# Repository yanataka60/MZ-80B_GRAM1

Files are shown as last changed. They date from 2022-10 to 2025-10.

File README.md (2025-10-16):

# MZ-80B GRAM1ボード

　MZ-80B OWNER'S MANUAL p65「図4-19 グラフィックメモリ1 MZ-8BG(オプション)」回路図から基板を起こしました。

　本体への装着方法は純正品と同じです。

## 回路図
　KiCadフォルダ内のMZ-80B_GRAM1.pdf参照

[回路図](https://github.com/yanataka60/MZ-80B_GRAM1/blob/main/KiCAD/MZ-80B_GRAM1.pdf)
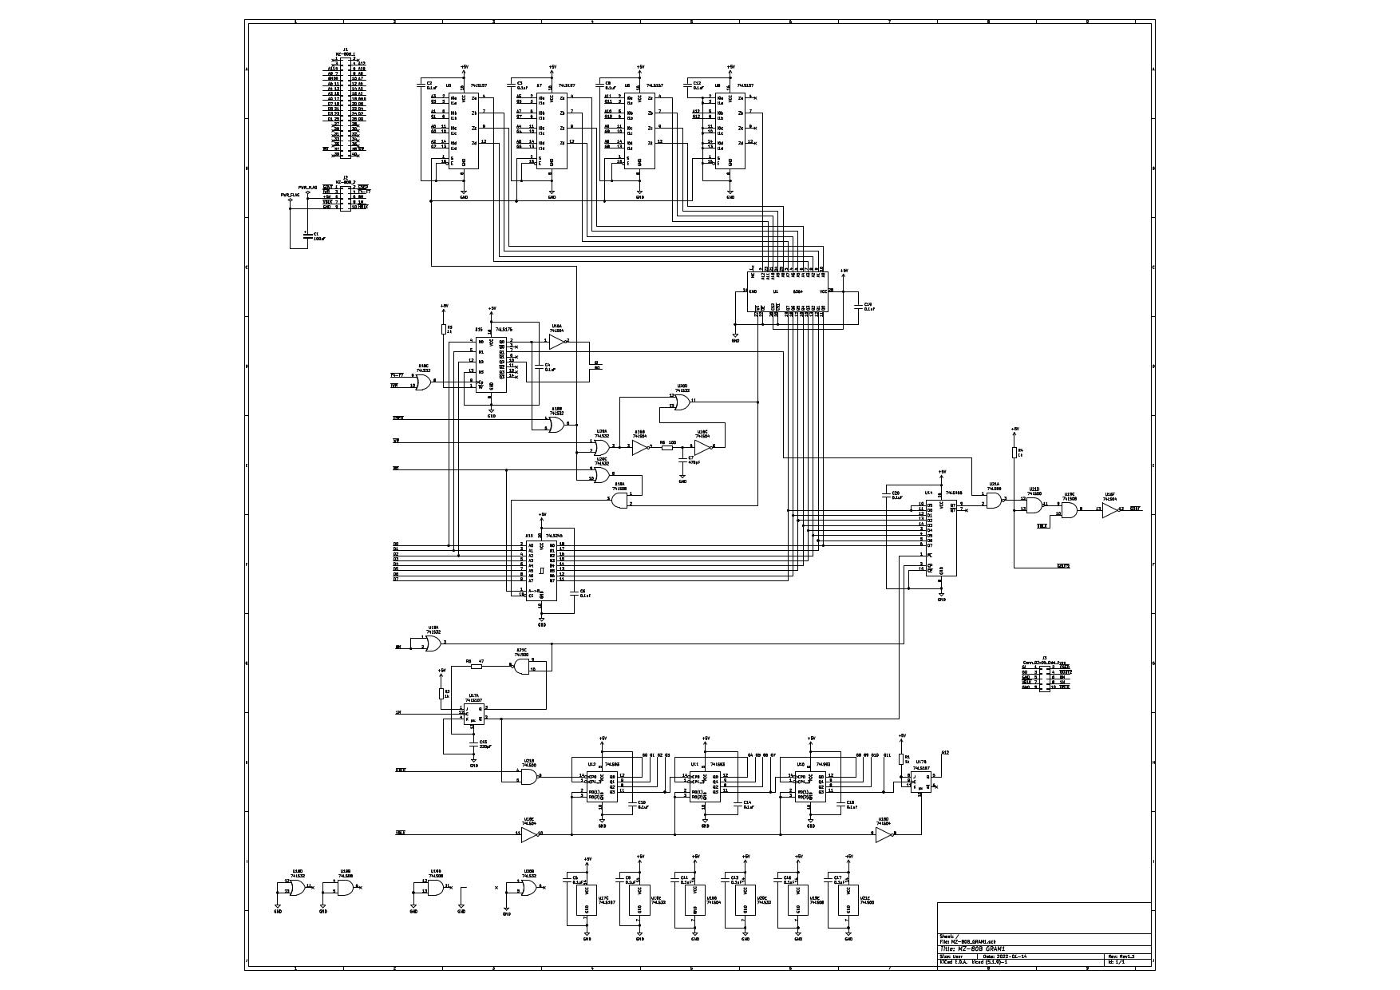
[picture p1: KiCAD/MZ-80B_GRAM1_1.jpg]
回路図


## 部品表
|番号|品名|数量|備考|
| --- | --- | --- | --- |
|C1|電解コンデンサ 16V100uF|1||
|C2-C6, C8-C14, C16-C20|積層セラミックコンデンサ 0.1uF|17||
|C7|コンデンサ 470pF|1||
|C15|コンデンサ 220pF|1||
|J1|2x20ピンヘッダ|1|秋月電子通商 PH-2x40SG等|
|J2|2x5ピンヘッダ|2|秋月電子通商 PH-2x40SG等|
|J3|2x5ピンヘッダ|2|GRAM2接続用 秋月電子通商 PH-2x40SG等|
|R1-R4|カーボン抵抗 1k|4||
|R5|カーボン抵抗 47Ω|1||
|R6|カーボン抵抗 100Ω|1||
|U1|8kx8 SRAM 6264|1|若松通商等|
|U5-U8|74LS157|4|若松通商等|
|U10-U12|74LS93|3|若松通商等|
|U13|74LS245|1|若松通商等|
|U14|74LS165|1|若松通商等|
|U15|74LS175|1|若松通商等|
|U16|74LS04|1|若松通商等|
|U17|74LS107|1|若松通商等|
|U18, U20|74LS32|2|若松通商等|
|U19|74LS08|1|若松通商等|
|U21|74LS00|1|若松通商等|
||2x20フラットケーブル|1|15cm程度|
||2x5フラットケーブル|1|20cm程度|

## ボードの完成写真
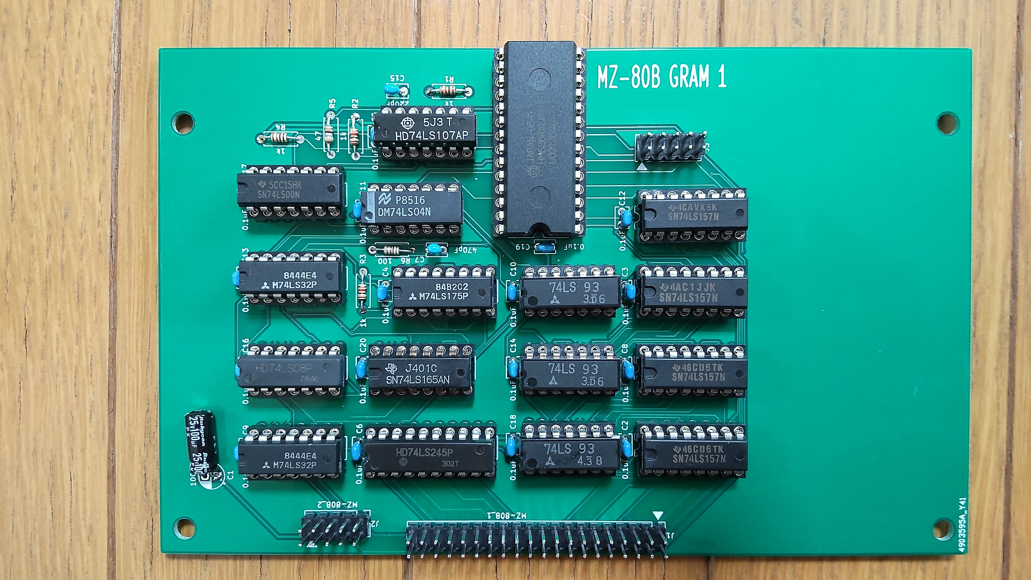
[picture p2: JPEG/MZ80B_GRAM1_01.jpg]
MZ80B_GRAM1_01


## 取付方法
ケーブルは1Pinの△マークを合わせて接続します。マザーボート上で2x5Pinケーブルなら手前左に1Pinの△マークがあり、2x20Pinケーブルは、右奥に1Pinの△マークがあります。

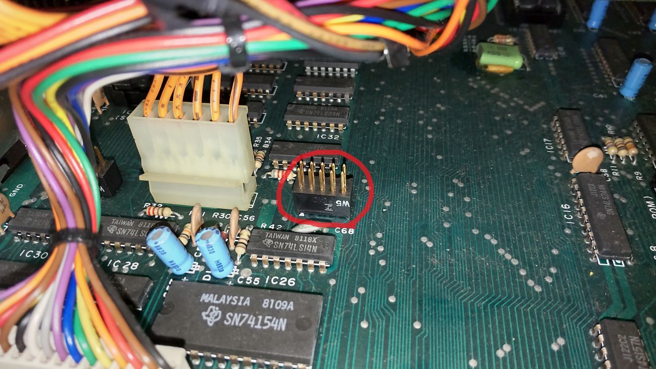
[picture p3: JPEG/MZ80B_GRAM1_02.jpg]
MZ80B_GRAM1_02


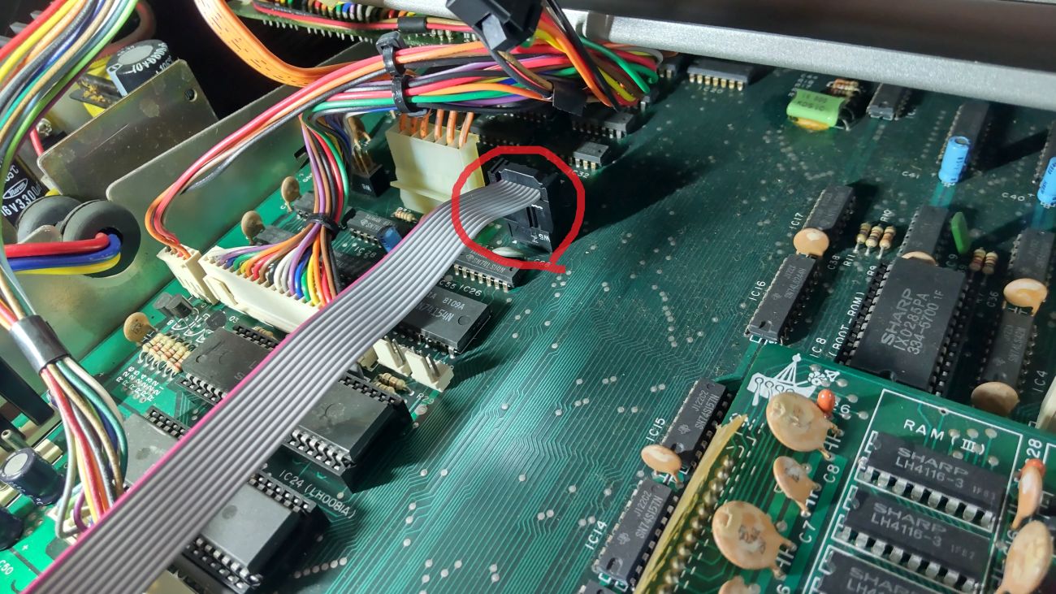
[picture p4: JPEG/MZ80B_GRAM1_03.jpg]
MZ80B_GRAM1_03


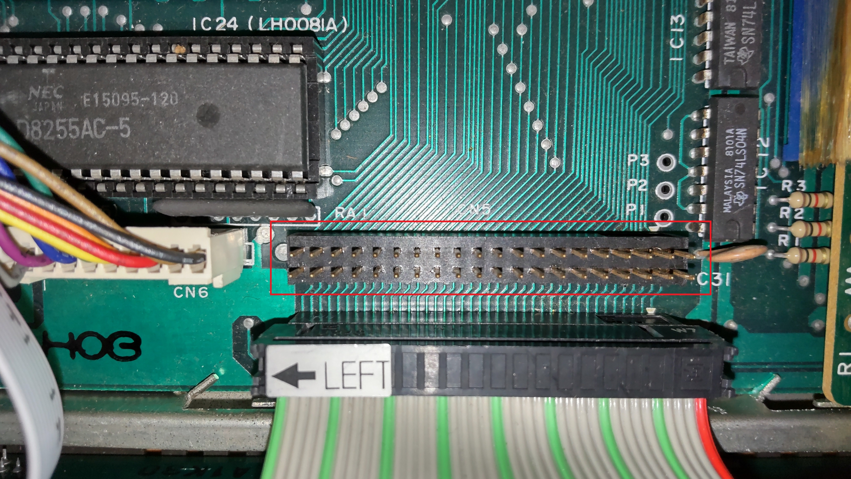
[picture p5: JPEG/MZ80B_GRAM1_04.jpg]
MZ80B_GRAM1_04


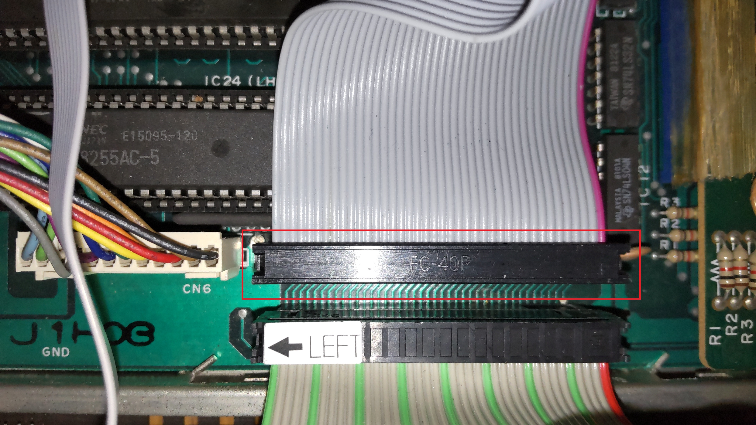
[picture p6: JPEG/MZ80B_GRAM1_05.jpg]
MZ80B_GRAM1_05


上筐体の裏側にGRAM1ボードを挿し込みます。

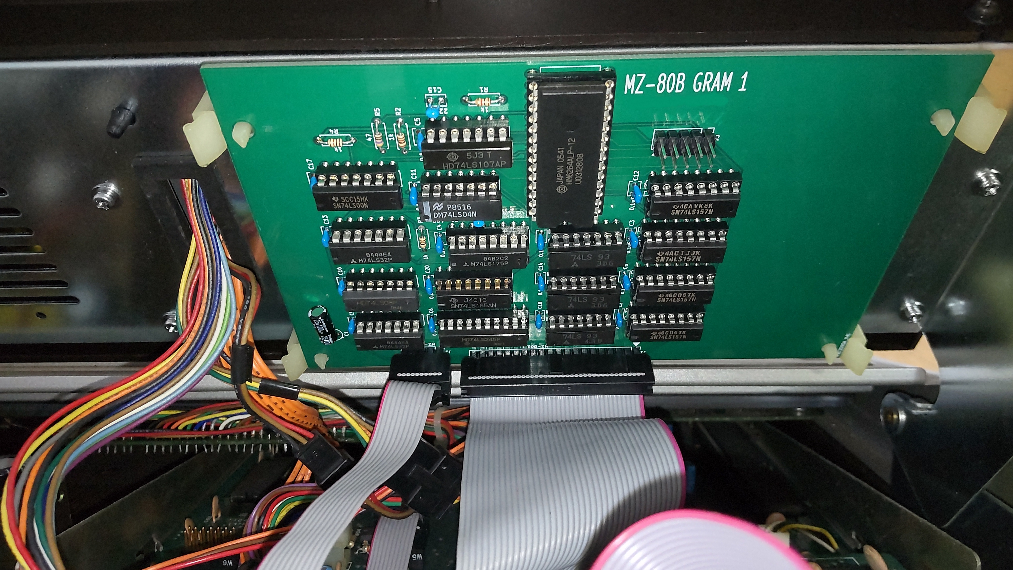
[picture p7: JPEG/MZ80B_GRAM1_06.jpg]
MZ80B_GRAM1_06


## 追記
2025.10.10 回路図のpdfファイルを追加した。

2025.10.15 J3は使用しないので部品表を修正。

2025.10.16 すみません。GRAM2を使うときにはJ3必要でした。

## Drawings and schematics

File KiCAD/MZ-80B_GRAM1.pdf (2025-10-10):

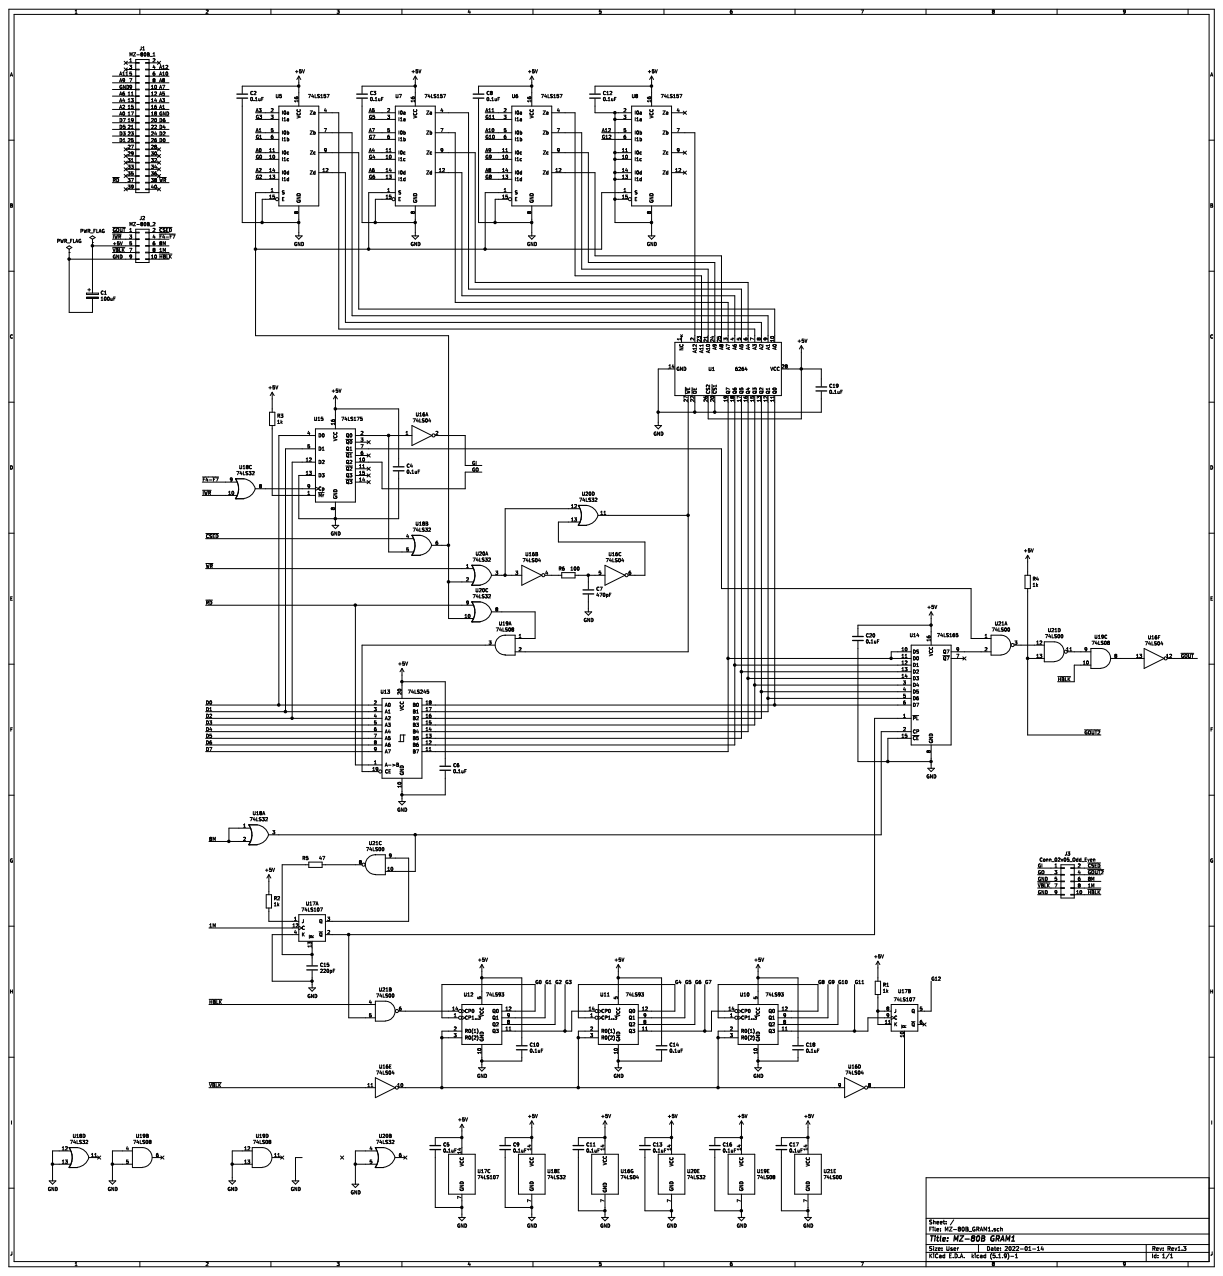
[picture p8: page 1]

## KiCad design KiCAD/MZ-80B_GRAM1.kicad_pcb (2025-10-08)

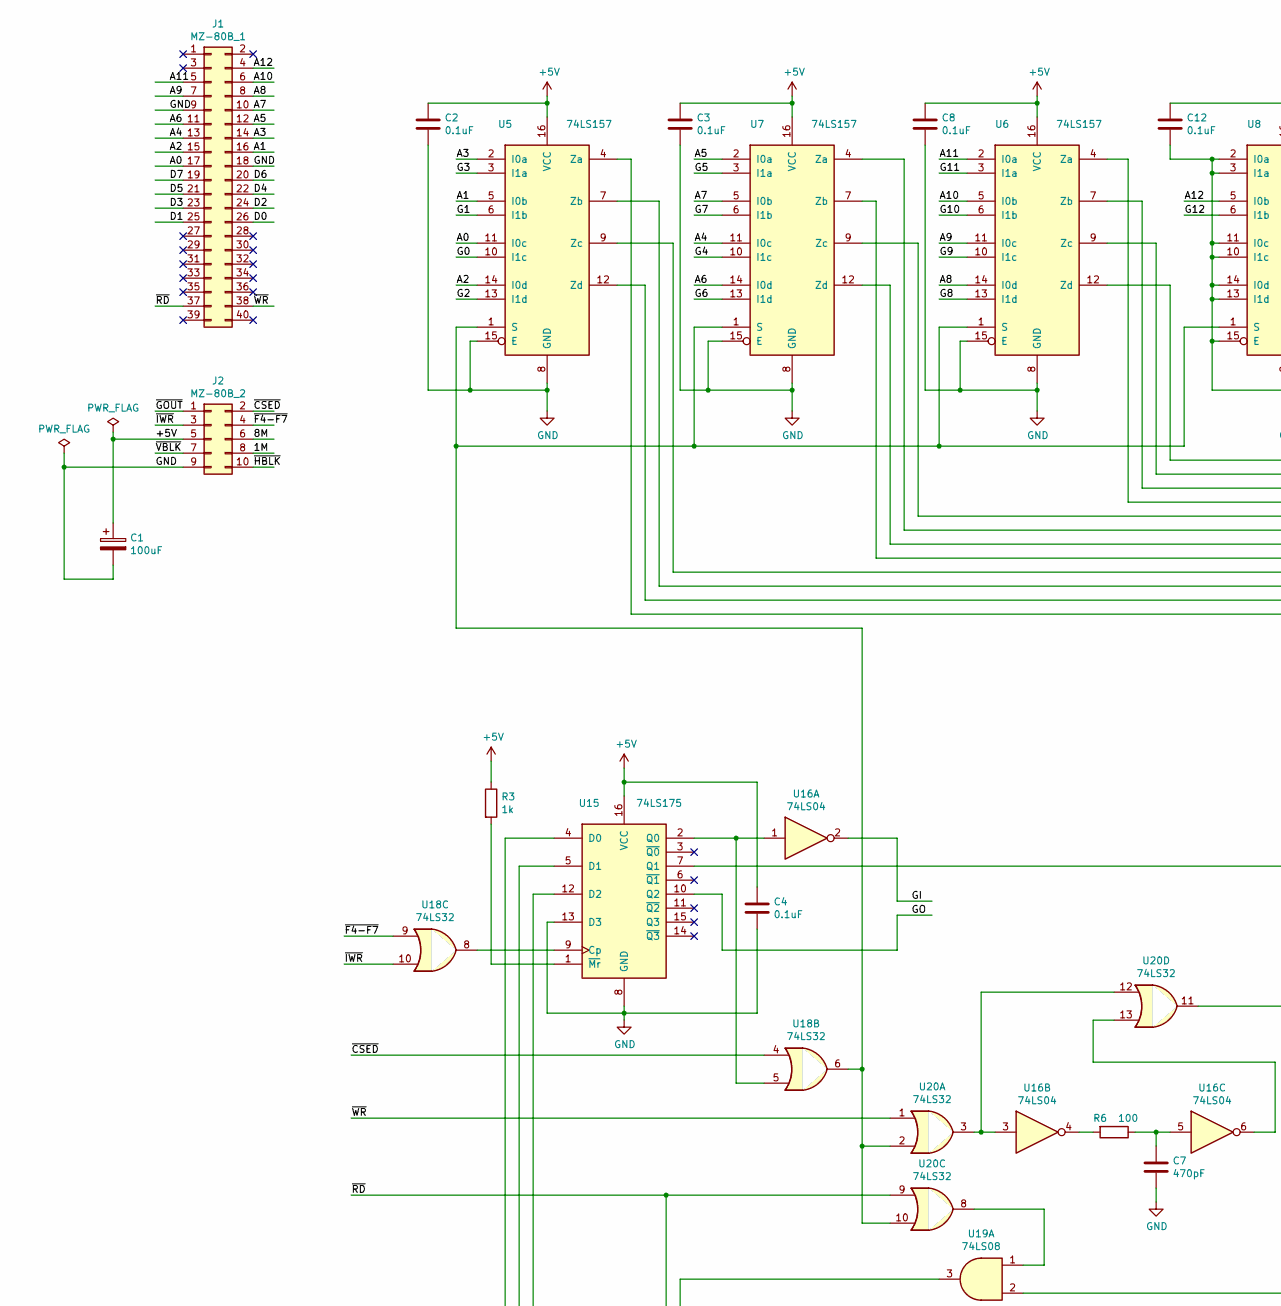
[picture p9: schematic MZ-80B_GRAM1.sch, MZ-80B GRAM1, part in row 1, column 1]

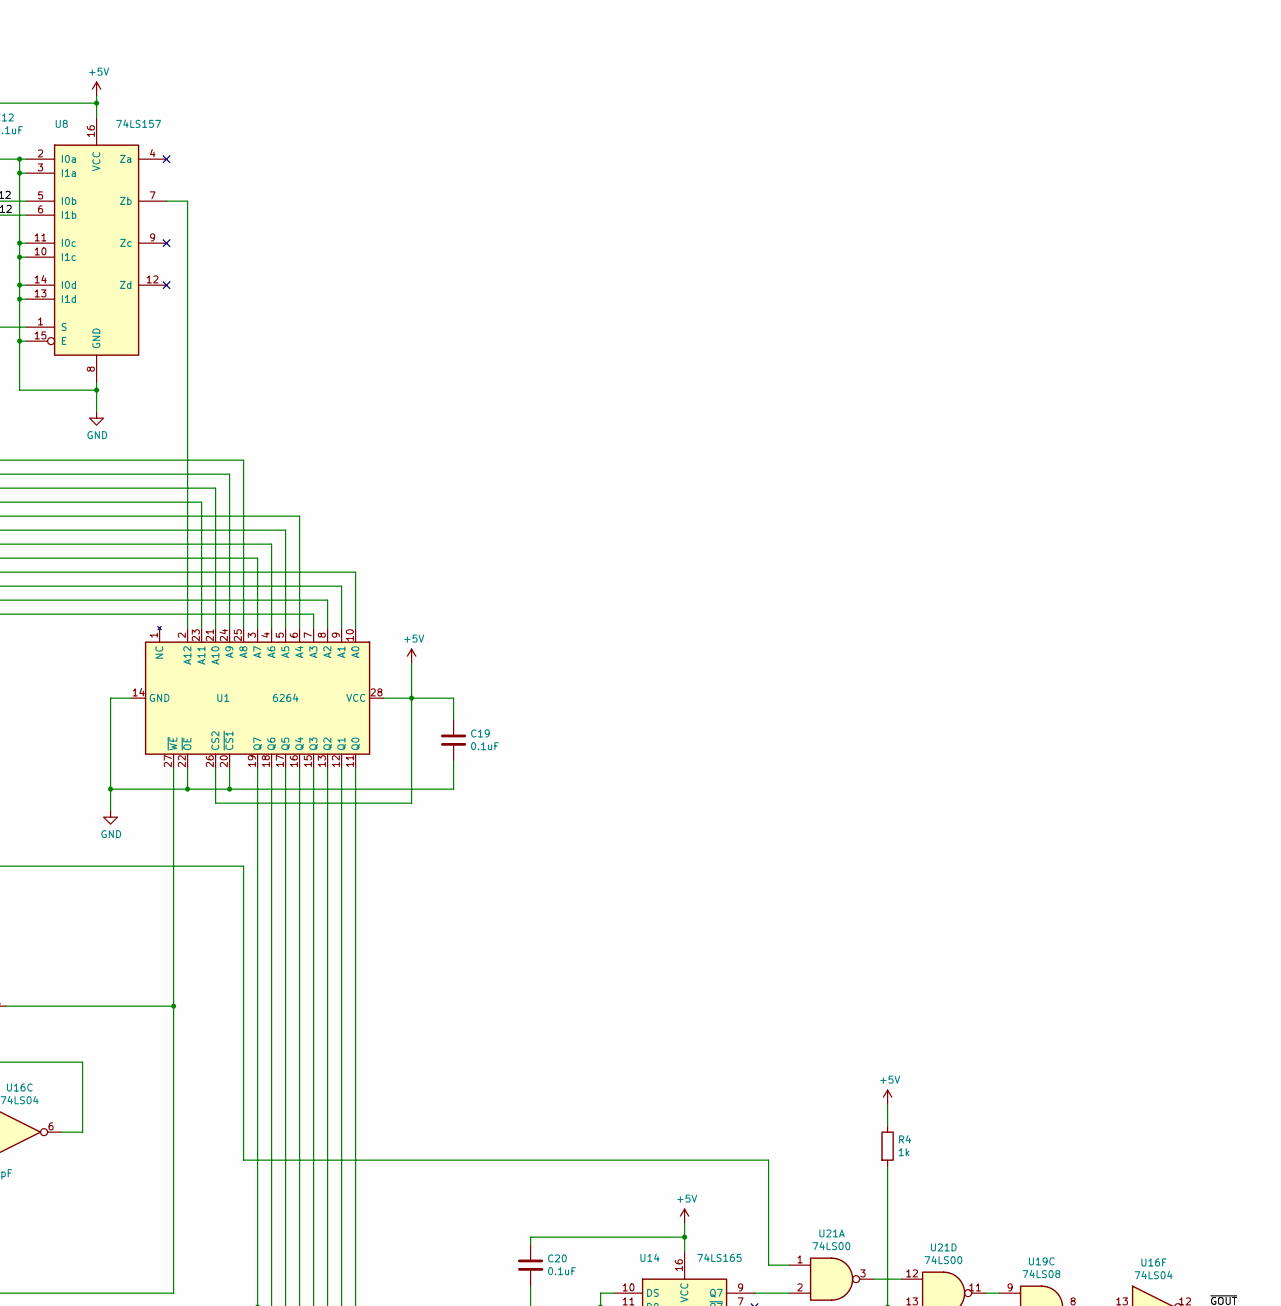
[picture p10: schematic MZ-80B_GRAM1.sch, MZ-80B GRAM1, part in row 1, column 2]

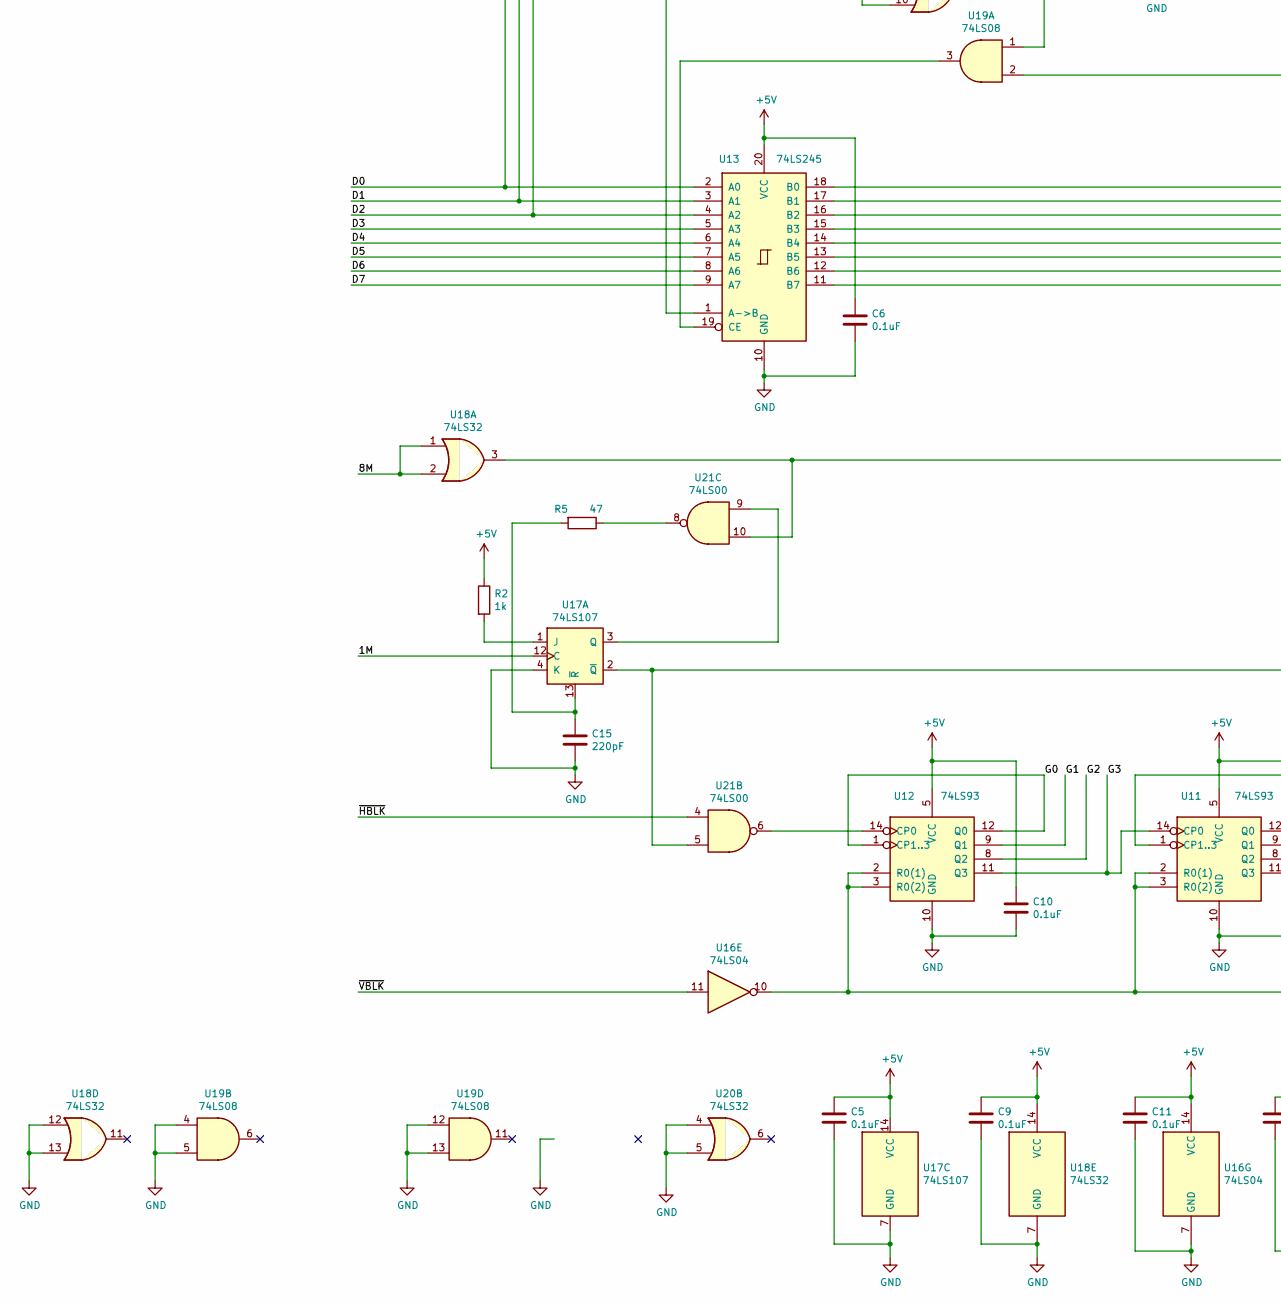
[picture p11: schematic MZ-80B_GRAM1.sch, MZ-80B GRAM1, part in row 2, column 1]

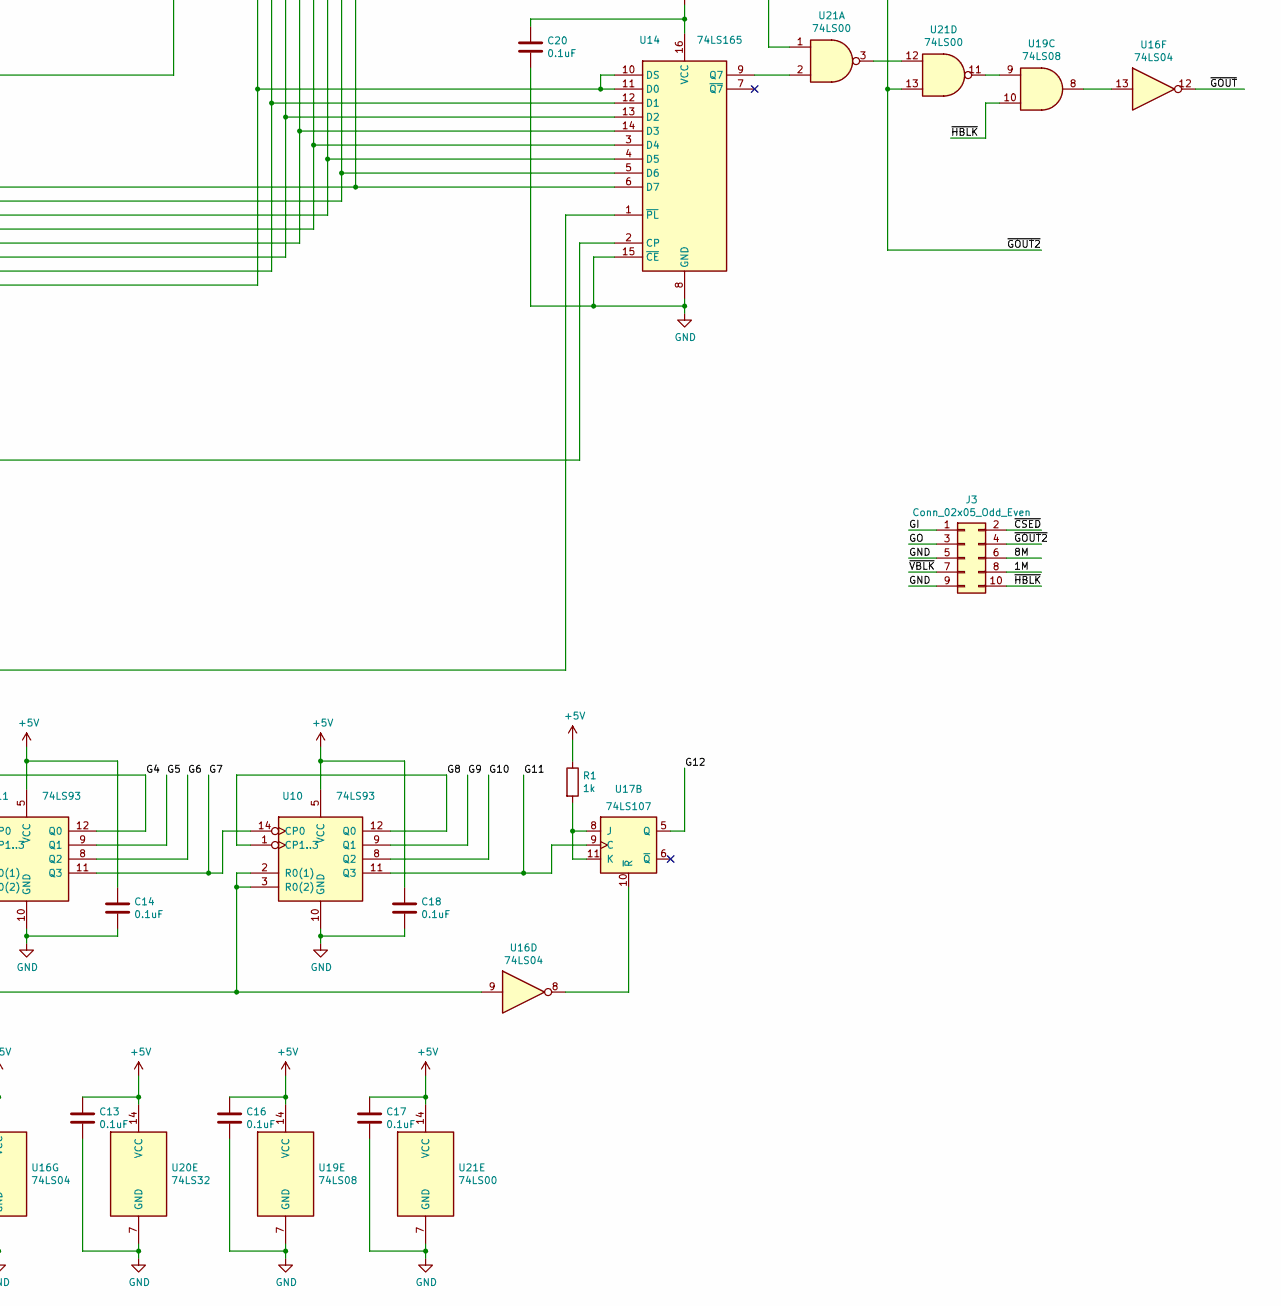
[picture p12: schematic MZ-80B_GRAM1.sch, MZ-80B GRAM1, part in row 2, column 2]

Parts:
C1: 100uF; CP_Radial_D5.0mm_P2.50mm
C2, C3, C4, C5, C6, C8, C9, C10, C11, C12, C13, C14, C16, C17, C18, C19, C20: 0.1uF; C_Rect_L4.0mm_W2.5mm_P2.50mm
C7: 470pF; C_Rect_L4.0mm_W2.5mm_P2.50mm
C15: 220pF; C_Rect_L4.0mm_W2.5mm_P2.50mm
J1: MZ-80B_1; PinHeader_2x20_P2.54mm_Vertical
J2: MZ-80B_2; PinHeader_2x05_P2.54mm_Vertical
J3: Conn_02x05_Odd_Even; PinHeader_2x05_P2.54mm_Vertical
R1, R2, R3, R4: 1k; R_Axial_DIN0207_L6.3mm_D2.5mm_P7.62mm_Horizontal
R5: 47; R_Axial_DIN0207_L6.3mm_D2.5mm_P7.62mm_Horizontal
R6: 100; R_Axial_DIN0207_L6.3mm_D2.5mm_P7.62mm_Horizontal
U1: 6264; DIP-28_W15.24mm_LongPads
U5, U6, U7, U8: 74LS157; DIP-16_W7.62mm_LongPads
U10, U11, U12: 74LS93; DIP-14_W7.62mm_LongPads
U13: 74LS245; DIP-20_W7.62mm_LongPads
U14: 74LS165; DIP-16_W7.62mm_LongPads
U15: 74LS175; DIP-16_W7.62mm_LongPads
U16: 74LS04; DIP-14_W7.62mm_LongPads
U17: 74LS107; DIP-14_W7.62mm_LongPads
U18, U20: 74LS32; DIP-14_W7.62mm_LongPads
U19: 74LS08; DIP-14_W7.62mm_LongPads
U21: 74LS00; DIP-14_W7.62mm_LongPads

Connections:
+5V: C1.1, C2.1, C3.1, C4.1, C5.1, C6.1, C8.1, C9.1, C10.1, C11.1, C12.1, C13.1, C14.1, C16.1, C17.1, C18.1, C19.1, C20.1, J2.5, R1.1, R2.1, R3.1, R4.1, U1.26 (CS2), U1.28 (VCC), U5.16 (VCC), U6.16 (VCC), U7.16 (VCC), U8.16 (VCC), U10.5 (VCC), U11.5 (VCC), U12.5 (VCC), U13.20 (VCC), U14.16 (VCC), U15.16 (VCC), U16.14 (VCC), U17.14 (VCC), U18.14 (VCC), U19.14 (VCC), U20.14 (VCC), U21.14 (VCC)
/1M: J2.8, J3.8, U17.12 (C)
/8M: J2.6, J3.6, U18.1, U18.2
/A0: J1.17, U5.11 (I0c)
/A1: J1.16, U5.5 (I0b)
/A2: J1.15, U5.14 (I0d)
/A3: J1.14, U5.2 (I0a)
/A4: J1.13, U7.11 (I0c)
/A5: J1.12, U7.2 (I0a)
/A6: J1.11, U7.14 (I0d)
/A7: J1.10, U7.5 (I0b)
/A8: J1.8, U6.14 (I0d)
/A9: J1.7, U6.11 (I0c)
/A10: J1.6, U6.5 (I0b)
/A11: J1.5, U6.2 (I0a)
/A12: J1.4, U8.5 (I0b)
/D0: J1.26, U13.2 (A0), U15.4 (D0)
/D1: J1.25, U13.3 (A1), U15.5 (D1)
/D2: J1.24, U13.4 (A2), U15.12 (D2)
/D3: J1.23, U13.5 (A3)
/D4: J1.22, U13.6 (A4)
/D5: J1.21, U13.7 (A5)
/D6: J1.20, U13.8 (A6)
/D7: J1.19, U13.9 (A7)
/G0: U5.10 (I1c), U12.1 (CP1..3), U12.12 (Q0)
/G1: U5.6 (I1b), U12.9 (Q1)
/G2: U5.13 (I1d), U12.8 (Q2)
/G3: U5.3 (I1a), U11.14 (CP0), U12.11 (Q3)
/G4: U7.10 (I1c), U11.1 (CP1..3), U11.12 (Q0)
/G5: U7.3 (I1a), U11.9 (Q1)
/G6: U7.13 (I1d), U11.8 (Q2)
/G7: U7.6 (I1b), U10.14 (CP0), U11.11 (Q3)
/G8: U6.13 (I1d), U10.1 (CP1..3), U10.12 (Q0)
/G9: U6.10 (I1c), U10.9 (Q1)
/G10: U6.6 (I1b), U10.8 (Q2)
/G11: U6.3 (I1a), U10.11 (Q3), U17.9 (C)
/G12: U8.6 (I1b), U17.5 (Q)
/GI: J3.1, U16.2
/GO: J3.3, U15.10 (Q2)
/~CSED: J2.2, J3.2, U18.4
/~F4-F7: J2.4, U18.9
/~GOUT: J2.1, U16.12
/~GOUT2: J3.4, R4.2, U21.13
/~HBLK: J2.10, J3.10, U19.10, U21.4
/~IWR: J2.3, U18.10
/~RD: J1.37, U13.1 (A->B), U20.9
/~VBLK: J2.7, J3.7, U16.11
/~WR: J1.38, U20.1
GND: C1.2, C2.2, C3.2, C4.2, C5.2, C6.2, C7.2, C8.2, C9.2, C10.2, C11.2, C12.2, C13.2, C14.2, C15.2, C16.2, C17.2, C18.2, C19.2, C20.2, J1.9, J1.18, J2.9, J3.5, J3.9, U1.14 (GND), U1.20 (~CS1), U1.22 (~OE), U5.8 (GND), U5.15 (E), U6.8 (GND), U6.15 (E), U7.8 (GND), U7.15 (E), U8.2 (I0a), U8.3 (I1a), U8.8 (GND), U8.10 (I1c), U8.11 (I0c), U8.13 (I1d), U8.14 (I0d), U8.15 (E), U10.10 (GND), U11.10 (GND), U12.10 (GND), U13.10 (GND), U14.8 (GND), U14.15 (~CE), U15.8 (GND), U15.13 (D3), U16.7 (GND), U17.4 (K), U17.7 (GND), U18.7 (GND), U18.12, U18.13, U19.4, U19.5, U19.7 (GND), U19.12, U19.13, U20.4, U20.5, U20.7 (GND), U21.7 (GND)
unnamed: C7.1, R6.1, U16.5
unnamed: C15.1, R5.2, U17.13 (~R)
unnamed: R1.2, U17.8 (J), U17.11 (K)
unnamed: R2.2, U17.1 (J)
unnamed: R3.2, U15.1 (~Mr)
unnamed: R5.1, U21.8
unnamed: R6.2, U16.4
unnamed: U1.2 (A12), U8.7 (Zb)
unnamed: U1.3 (A7), U7.7 (Zb)
unnamed: U1.4 (A6), U7.12 (Zd)
unnamed: U1.5 (A5), U7.4 (Za)
unnamed: U1.6 (A4), U7.9 (Zc)
unnamed: U1.7 (A3), U5.4 (Za)
unnamed: U1.8 (A2), U5.12 (Zd)
unnamed: U1.9 (A1), U5.7 (Zb)
unnamed: U1.10 (A0), U5.9 (Zc)
unnamed: U1.11 (Q0), U13.18 (B0), U14.6 (D7)
unnamed: U1.12 (Q1), U13.17 (B1), U14.5 (D6)
unnamed: U1.13 (Q2), U13.16 (B2), U14.4 (D5)
unnamed: U1.15 (Q3), U13.15 (B3), U14.3 (D4)
unnamed: U1.16 (Q4), U13.14 (B4), U14.14 (D3)
unnamed: U1.17 (Q5), U13.13 (B5), U14.13 (D2)
unnamed: U1.18 (Q6), U13.12 (B6), U14.12 (D1)
unnamed: U1.19 (Q7), U13.11 (B7), U14.10 (DS), U14.11 (D0)
unnamed: U1.21 (A10), U6.7 (Zb)
unnamed: U1.23 (A11), U6.4 (Za)
unnamed: U1.24 (A9), U6.9 (Zc)
unnamed: U1.25 (A8), U6.12 (Zd)
unnamed: U1.27 (~WE), U19.2, U20.11
unnamed: U10.2 (R0(1)), U10.3 (R0(2)), U11.2 (R0(1)), U11.3 (R0(2)), U12.2 (R0(1)), U12.3 (R0(2)), U16.9, U16.10
unnamed: U12.14 (CP0), U21.6
unnamed: U13.19 (CE), U19.3
unnamed: U14.1 (~PL), U17.2 (~Q), U21.5
unnamed: U14.2 (CP), U18.3, U21.10
unnamed: U14.9 (Q7), U21.2
unnamed: U15.2 (Q0), U16.1, U18.5
unnamed: U15.7 (Q1), U21.1
unnamed: U15.9 (Cp), U18.8
unnamed: U16.3, U20.3, U20.12
unnamed: U16.6, U20.13
unnamed: U16.8, U17.10 (~R)
unnamed: U16.13, U19.8
unnamed: U17.3 (Q), U21.9
unnamed: U5.1 (S), U6.1 (S), U7.1 (S), U8.1 (S), U18.6, U20.2, U20.10
unnamed: U19.1, U20.8
unnamed: U19.9, U21.11
unnamed: U21.3, U21.12

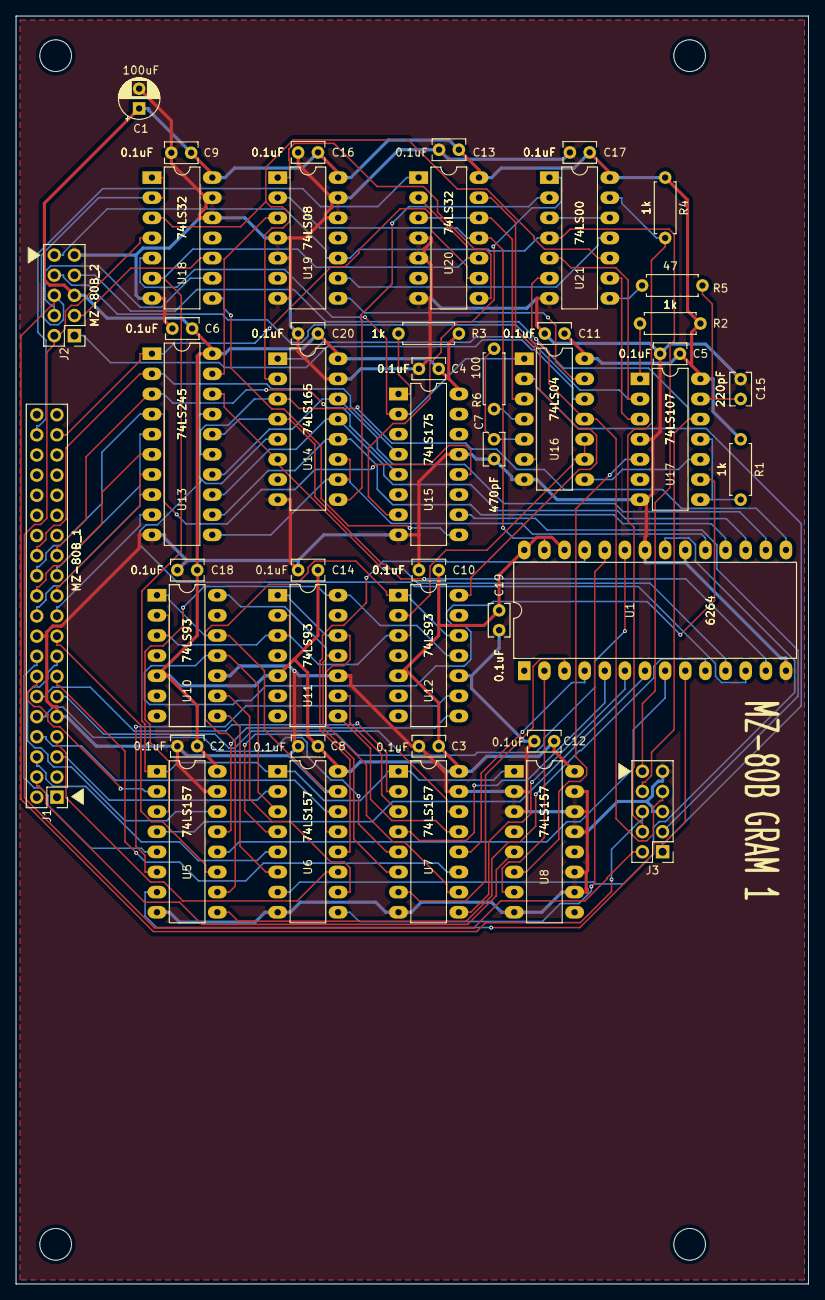
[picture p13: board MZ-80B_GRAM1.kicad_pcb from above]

Board: 2 copper layers, 100.0 x 160.0 mm, 50 parts (0 on the bottom side), 96 nets.

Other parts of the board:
MH1, MH2, MH3, MH4: MountingHole_4mm
